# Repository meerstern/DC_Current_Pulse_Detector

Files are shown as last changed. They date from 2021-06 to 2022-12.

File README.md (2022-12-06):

# DC電流パルス検知基板
DC Current Pulse Detector with CT Sensor

## 概要 
  * 直流信号線のON、OFF状態をクランプ式CTセンサで検出するための変換基板です 
  * 本変換基板とクランプ式CTセンサによって信号線を加工せずに直流信号線の状態を取得することができます  
  * 信号線ON/OFFによって発生するパルスをCTセンサで検出し、状態をラッチします 
  * ラッチ保持した状態(信号線のON/OFF状態)を1/0のデジタル信号として出力します  
  * 基板上の可変抵抗で状態を切り替えるパルス閾値を変更することができます  
  * 3000:1の巻き線比のCTセンサを同梱しています  一般的なCTセンサでも置き換え可能です  
  * 信号線の電流に応じて閾値を変更することで5mA~50mA程度の信号線のON/OFF状態を出力できます  
  * 微弱な電流で誤検知する場合はCTセンサに信号線を複数回巻いて閾値を高く設定してください  
  * 電源3.0V~5.5V、コネクタはGrove互換コネクタです 
  * 出力はSTA1、STA2の2つあり、閾値が正しく設定されている場合、どちらか一方がONでもう片方はOFFとなります
  * STA1、STA2のON状態(LED D1とD2に対応)と信号線のON状態はCTセンサの向きによって変わります  
  * 基板サイズ30 x25mm、固定穴M3 x2 幅19mm  
  * 下記の図に示す様にCTセンサ白線をJ1の1番ピン、CTセンサ黒線J1の2番ピンに配線し、CTセンサのK→Ｌ電流を流した場合、  
  信号線ONでS1(LED1)がHighかつS2(LED2)がLowとなります。逆に信号線OFFでS1(LED1)がLowかつS2(LED2)がHighとなります。  

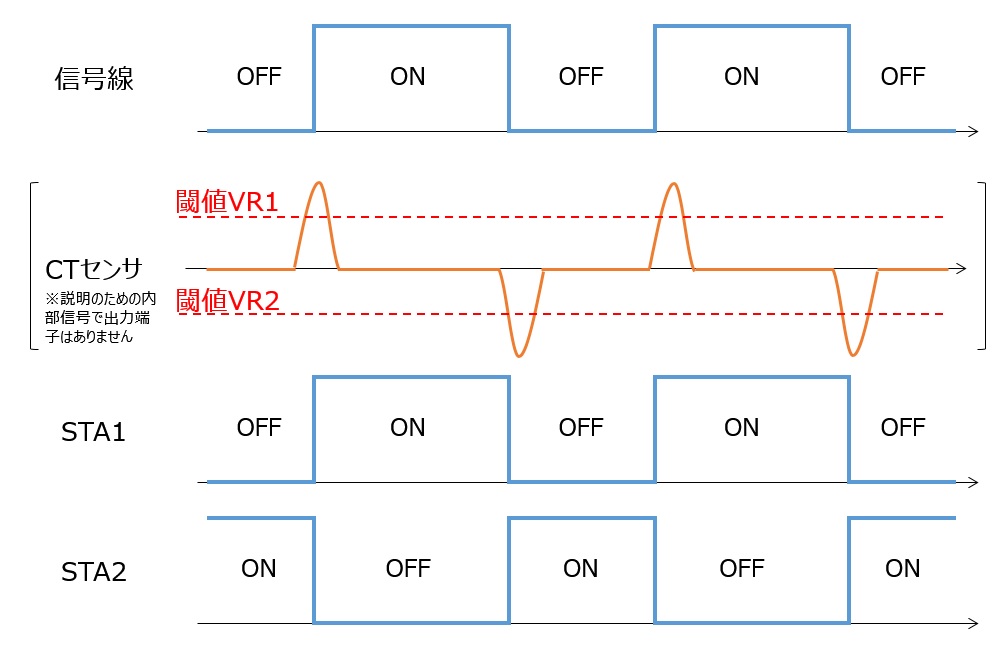
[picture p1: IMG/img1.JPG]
 
 
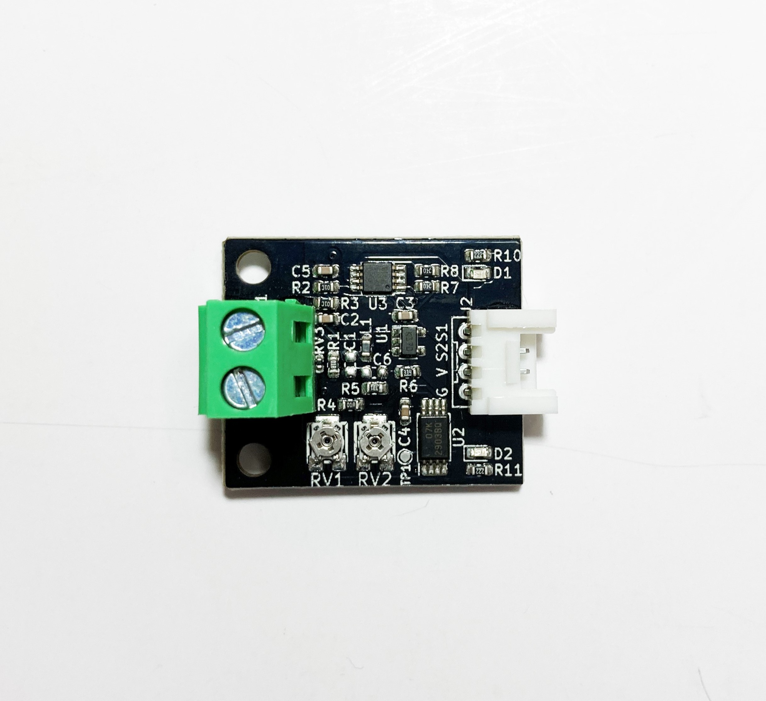
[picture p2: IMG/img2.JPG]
 

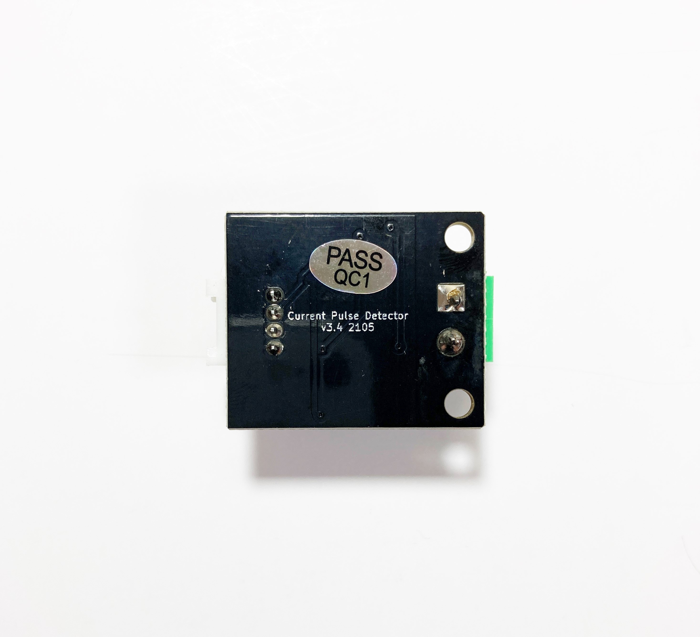
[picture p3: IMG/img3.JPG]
 
 
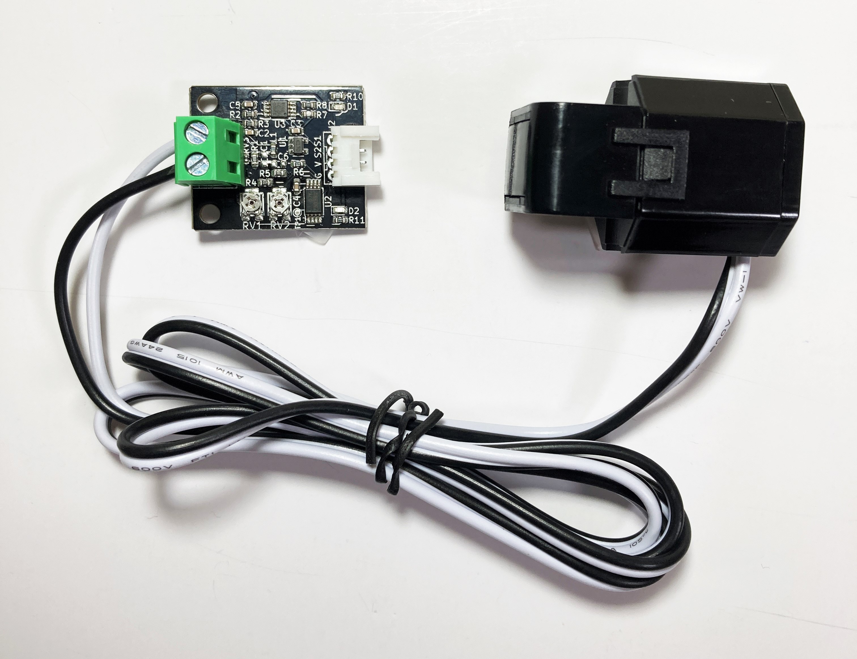
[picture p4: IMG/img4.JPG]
 
 
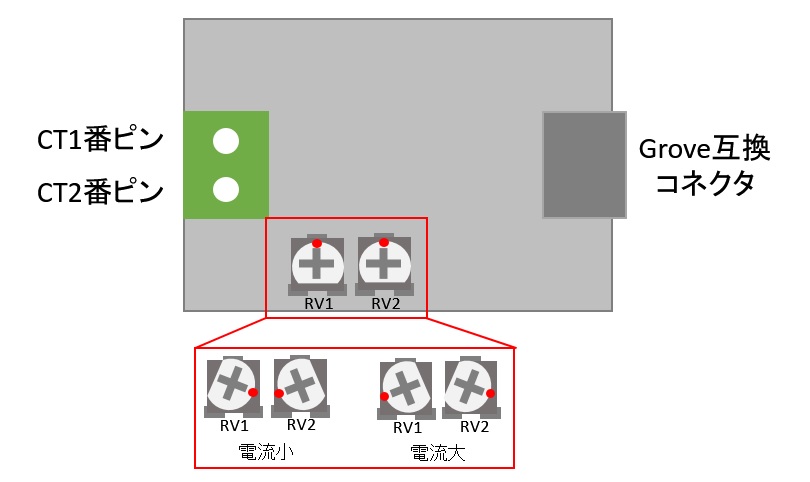
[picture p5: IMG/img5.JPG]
 
 
## 注意
  * 電源投入直後のデジタル出力状態は不定です  
  * 信号線ON/OFFによって発生するパルスの向きでON、OFFを検知するため、電源投入直後はSTA1、STA2の状態と信号状態が一致しません  
  * 電源投入後に信号線のONとOFFを1回繰り返すことで以降の信号線のON/OFF状態を保持して信号の状態をデジタル出力します  
  * 微弱な直流信号状態をCTセンサで簡易的に取得することを目的としており、10A以上の大電流のON/OFFの検出には使用しないでください  
  * 直流信号線のON/OFFの立上がり、立下りの勾配が緩やかな場合は検知できない場合があります  
  * STA1、STA2の両方がON状態の場合は閾値が正しく設定されていないため、可変抵抗を調整してください  
  * 信号線の電流が5mA前後の小さい場合やCTセンサの設置環境、配線の引き回し等の影響で誤検知する場合があります  
  * ノイズが多い環境では誤検知する可能性があります  ノイズ源から距離を保ち、CTセンサのケーブル長さを短くする等の対策を行ってください  
  * 信号状態を簡易的に取得することを目的としており、信頼性が求められる目的で使用しないでください  
  * 同梱CTセンサ(巻き線比3000:1,75A/25mA,7.5V以上保護 KCT-10)は納品タイミングによって予告なしに変更する場合があります  
  
## 販売サイト
  * [スイッチサイエンス][2]  

  MIT Lisense

[2]: https://www.switch-science.com/products/7396

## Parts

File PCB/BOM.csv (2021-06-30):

Elecrow PN | Parts | Value | Package | QTY | Digikey/Mouser/Manufacturer Part | Remark/ Link
 | U2 | LM2903BQP TSSOP8 | TSSOP-8_4.4x3mm_P0.65mm | 1 | 771-LVC2G00DP125
 | U3 | 74LVC2G00 | TSSOP-8_3x3mm_P0.65mm | 1 | 595-LM2903BIPWR
 | RV3 | Varistor | Fuse_0402_1005Metric | 1 | 810-AVR-M1005C080MC
C22775 | R4 | 100 | R_0603_1608Metric | 1
 | J2 | Grove | GROVE | 1 | 713-110990037
 | L1 | FB | L_0603_1608Metric | 1 | 81-BLM18SG331TN1D
C14663 | C5,C4,C3,C2 | 0.1u | C_0603_1608Metric | 4
 | U1 | LM321 | SOT-23-5 | 1 | 595-LM321LVIDBVR
 | RV2,RV1 | 5k | rcl-RTRIMCVR42A | 2 | 652-TC33X-2-502G
C25804 | R8,R7,R3,R2 | 10k | R_0603_1608Metric | 4
C23137 | R6 | 330k | R_0603_1608Metric | 1
C21190 | R1 | 1k | R_0603_1608Metric | 1
C4190 | R11,R10 | 2.2k | R_0603_1608Metric | 2
4040806A | D2,D1 | LED | LED_0603_1608Metric | 2
 | J1 | Sense | TerminalBlock_bornier-2_P5.08mm | 1 | 490-TB007-508-02BE
C23138 | R5 | 330 | R_0603_1608Metric | 1

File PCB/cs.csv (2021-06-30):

ID | 参照記号 | パッケージ | 数 | 名称 | Supplier and ref
1 | U2 | TSSOP-8_4.4x3mm_P0.65mm | 1 | LM2903BQP TSSOP8
2 | U3 | TSSOP-8_3x3mm_P0.65mm | 1 | 74LVC2G00
3 | TP1 | TestPoint_Pad_D1.0mm | 1 | OUT
4 | RV3 | Fuse_0402_1005Metric | 1 | Varistor
5 | R4 | R_0603_1608Metric | 1 | 0
6 | J2 | GROVE | 1 | Grove
7 | L1 | L_0603_1608Metric | 1 | FB
8 | C6,C5,C4,C3,C2 | C_0603_1608Metric | 5 | 0.1u
9 | U1 | SOT-23-5 | 1 | LM321
10 | RV2,RV1 | rcl-RTRIMCVR42A | 2 | 5k
11 | R8,R7,R3,R2 | R_0603_1608Metric | 4 | 10k
12 | R6 | R_0603_1608Metric | 1 | 330k
13 | R1 | R_0603_1608Metric | 1 | 1k
14 | H2,H1 | MountingHole_3.2mm_M3 | 2 | MountingHole
15 | R11,R10 | R_0603_1608Metric | 2 | 2.1k
16 | D2,D1 | LED_0603_1608Metric | 2 | LED
17 | C1 | C_0603_1608Metric | 1 | NM
18 | J1 | TerminalBlock_bornier-2_P5.08mm | 1 | Sense
19 | R5 | R_0603_1608Metric | 1 | 330

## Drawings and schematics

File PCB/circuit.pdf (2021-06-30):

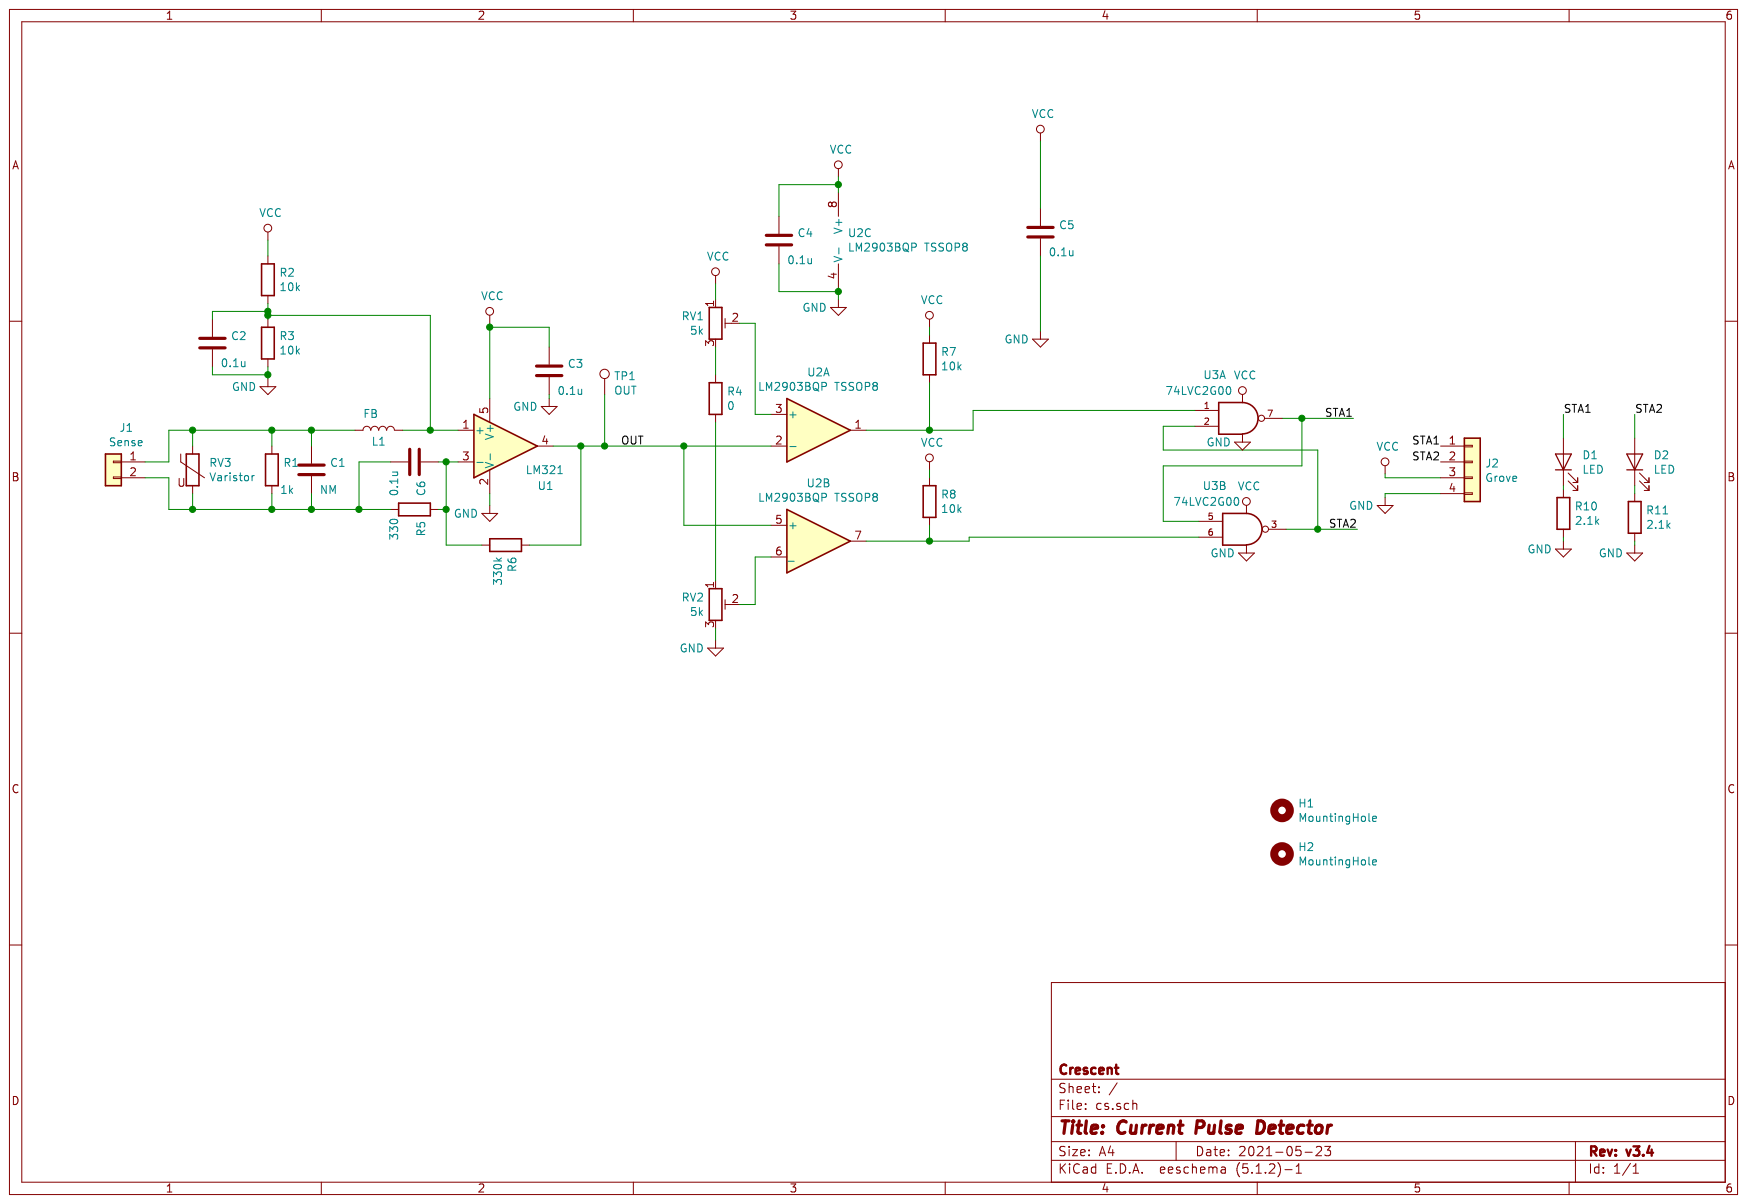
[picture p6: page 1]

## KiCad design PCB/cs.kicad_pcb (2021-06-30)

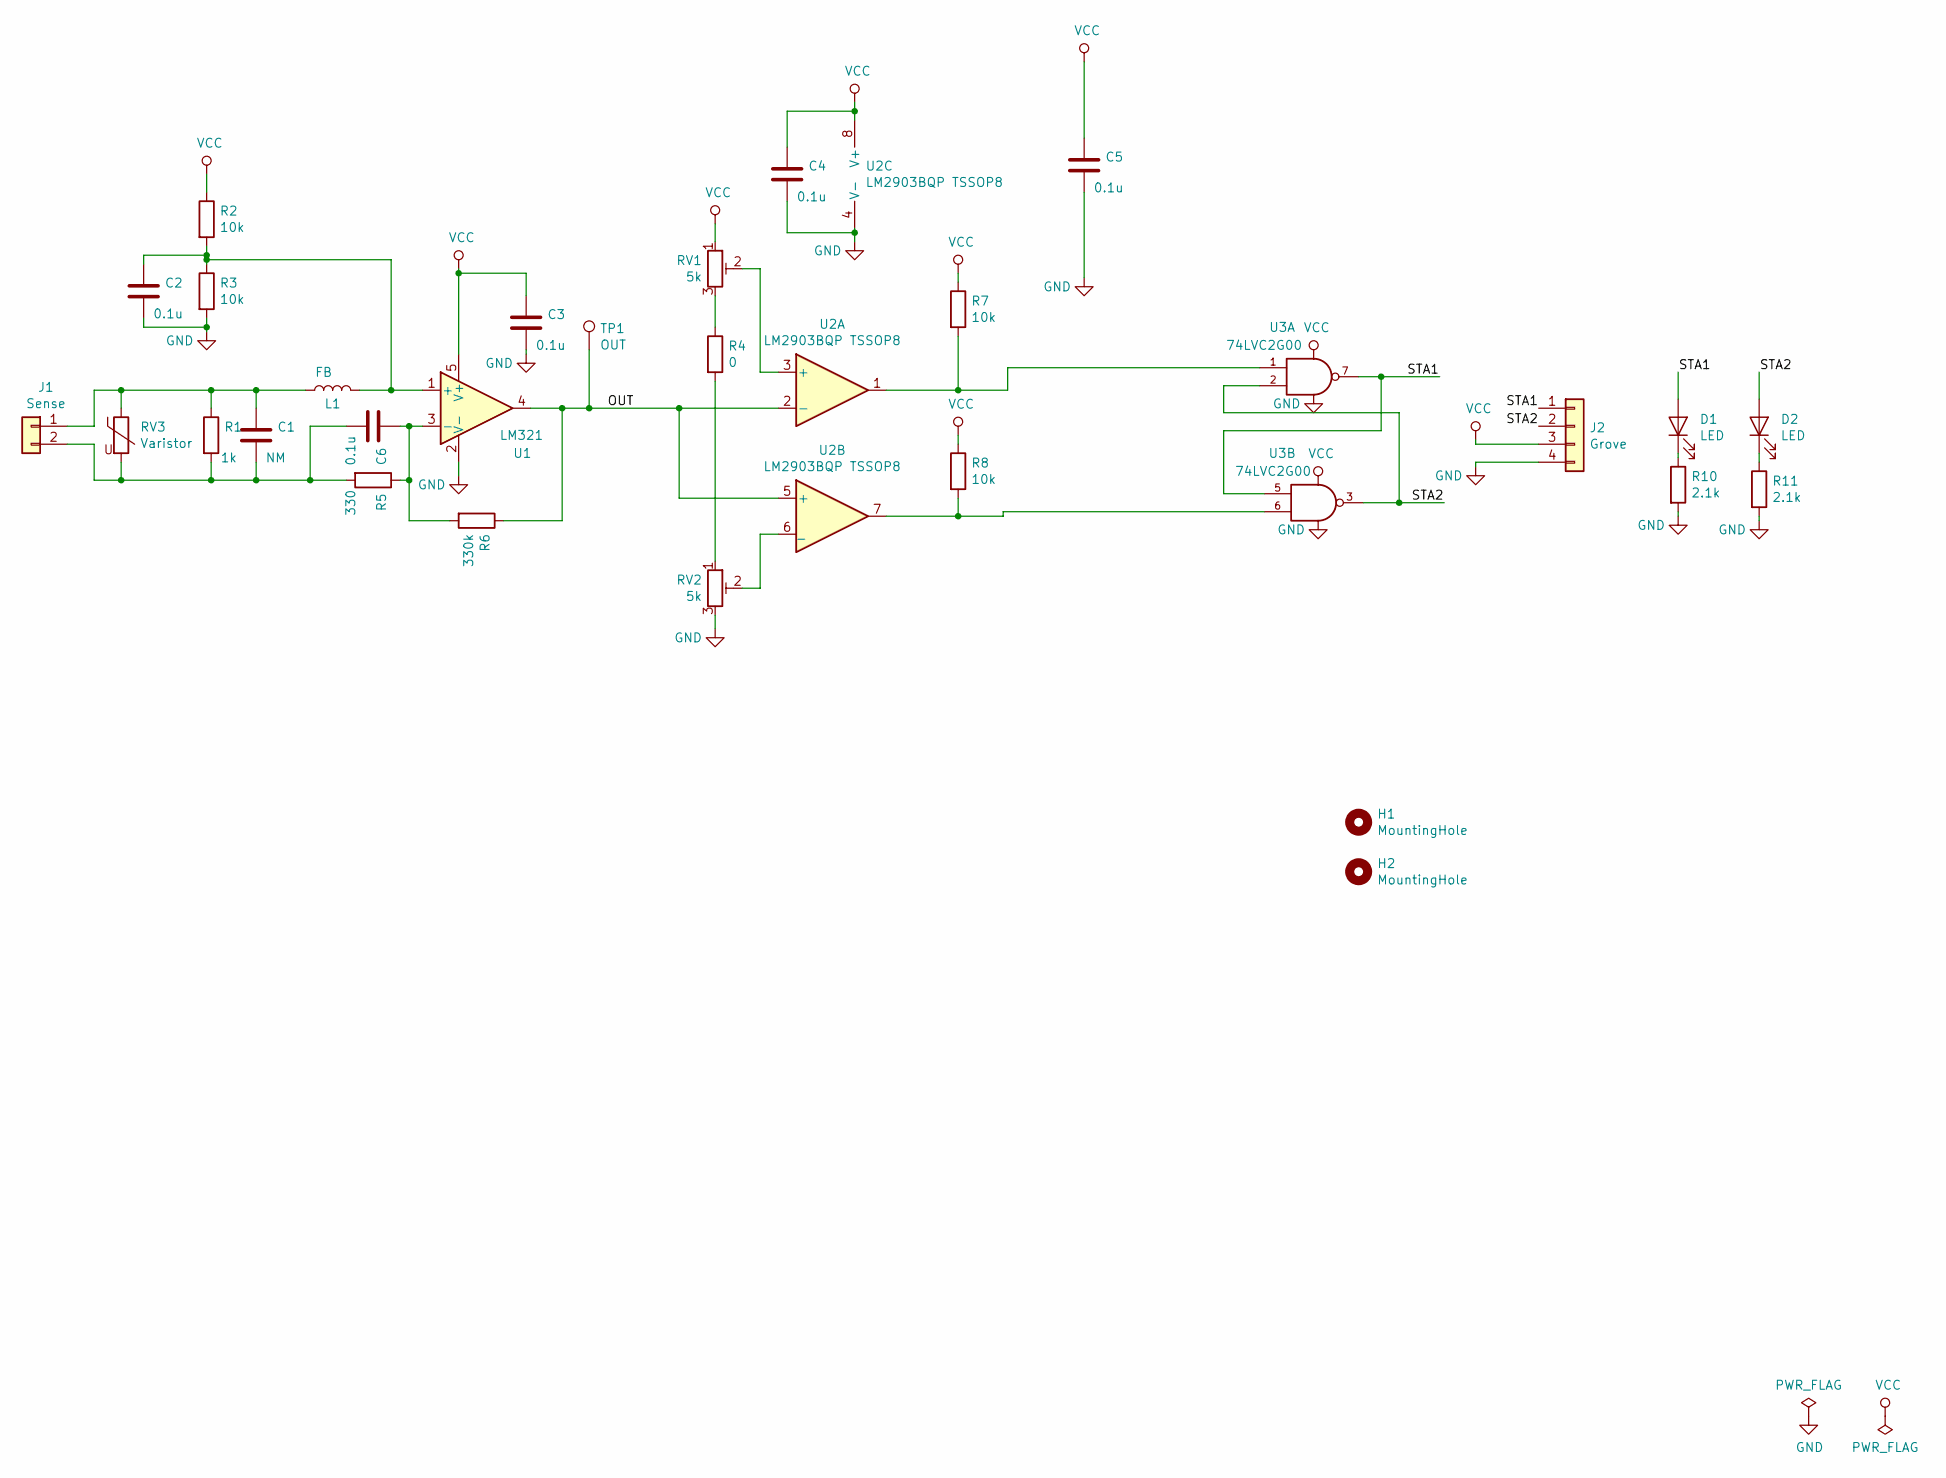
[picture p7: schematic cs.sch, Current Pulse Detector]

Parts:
C1: NM; C_0603_1608Metric
C2, C3, C4, C5, C6: 0.1u; C_0603_1608Metric
D1, D2: LED; LED_0603_1608Metric
H1, H2: MountingHole; MountingHole_3.2mm_M3
J1: Sense; TerminalBlock_bornier-2_P5.08mm
J2: Grove; GROVE
L1: FB; L_0603_1608Metric
R1: 1k; R_0603_1608Metric
R2, R3, R7, R8: 10k; R_0603_1608Metric
R4: 0; R_0603_1608Metric
R5: 330; R_0603_1608Metric
R6: 330k; R_0603_1608Metric
R10, R11: 2.1k; R_0603_1608Metric
RV1, RV2: 5k; rcl-RTRIMCVR42A
RV3: Varistor; Fuse_0402_1005Metric
TP1: OUT; TestPoint_Pad_D1.0mm
U1: LM321; SOT-23-5
U2: LM2903BQP TSSOP8; TSSOP-8_4.4x3mm_P0.65mm
U3: 74LVC2G00; TSSOP-8_3x3mm_P0.65mm

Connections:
/OUT: R6.1, TP1.1, U1.4, U2.2 (-), U2.5 (+)
/STA1: D1.2 (A), J2.1, U3.5, U3.7
/STA2: D2.2 (A), J2.2, U3.2, U3.3
GND: C2.2, C3.2, C4.2, C5.2, J2.4, R3.2, R10.2, R11.2, RV2.3, U1.2 (V-), U2.4 (V-), U3.4 (GND)
unnamed: C1.1, J1.1, L1.1, R1.1, RV3.1
unnamed: C1.2, C6.2, J1.2, R1.2, R5.2, RV3.2
unnamed: C2.1, L1.2, R2.2, R3.1, U1.1 (+)
unnamed: C6.1, R5.1, R6.2, U1.3 (-)
unnamed: D1.1 (K), R10.1
unnamed: D2.1 (K), R11.1
unnamed: R4.1, RV1.3
unnamed: R4.2, RV2.1
unnamed: R7.2, U2.1, U3.1
unnamed: R8.2, U2.7, U3.6
unnamed: RV1.2, U2.3 (+)
unnamed: RV2.2, U2.6 (_)
VCC: C3.1, C4.1, C5.1, J2.3, R2.1, R7.1, R8.1, RV1.1, U1.5 (V+), U2.8 (V+), U3.8 (VCC)

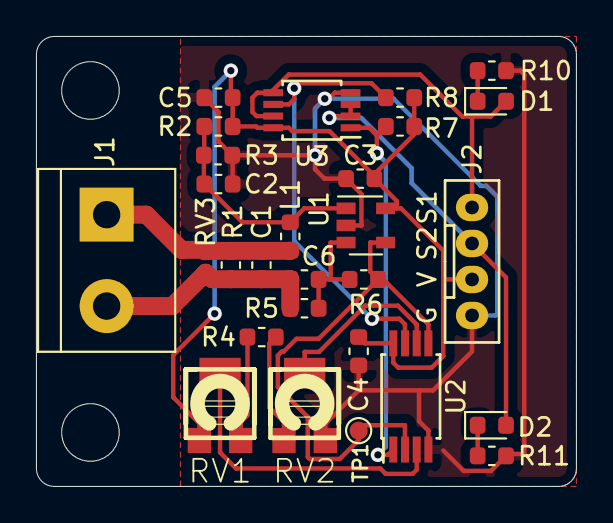
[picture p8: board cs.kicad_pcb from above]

Board: 2 copper layers, 30.0 x 25.0 mm, 30 parts (0 on the bottom side), 17 nets.
